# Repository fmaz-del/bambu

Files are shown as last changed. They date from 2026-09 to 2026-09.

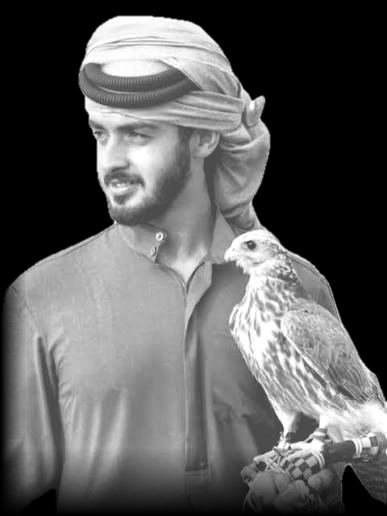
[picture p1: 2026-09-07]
prepared.png

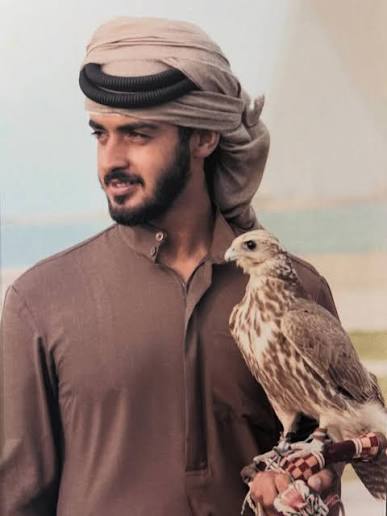
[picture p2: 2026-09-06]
portrait_source.jpg

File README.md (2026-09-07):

# xBloom face cover — picture embossing

Tooling to put a picture on the front of the xBloom Studio cover
(`xbloom_face_v1.5_.3mf`), or on any other STL/3MF model.

## The model

`xbloom_face_v1.5_.3mf` is a Bambu Studio project holding one object,
`xbloom face with straps v1.stl` (4552 triangles), laid on the plate so that
**the visible outer face of the cover points down, at Z = 0**.

Measured from the mesh:

| | |
|---|---|
| overall | 172.4 × 215.7 × 79.9 mm |
| panel wall thickness | 2.9 mm |
| **front panel (flat, usable)** | **X 51.8 … 135.0, Y 16.6 … 232.3 → 83.2 × 215.7 mm** |
| right wing | X 138 … 220 — carries 3 × Ø10 mm holes and a vent slot array |

So the picture goes on the `bottom` face (outward normal −Z), restricted to the
left-hand region — the right-hand part of that face is the side wing and must
stay clear.

The mesh is closed but **not manifold**: 8 bodies, 135 edges shared by 4 faces,
18 duplicate faces, and ~95 zero-thickness triangle pairs left over from the
striped variant. A true CSG boolean therefore fails, and the tool falls back to
merging the shells — slicers union overlapping solids, so an emboss still
prints correctly. An *engrave* would need a repaired mesh first.

## Result

`xbloom_face_raised_0.1mm.3mf` — **print this one.** The portrait stands out of
the panel: the whole panel is lowered 1.4 mm and the figure rises back to the
original surface, 83.2 x 108 mm, seated at the bottom and running the full
panel width. The project's layer height is set to 0.1 mm.

`xbloom_face_raised_0.2mm.3mf` is the same mesh on the original 0.2 mm profile.

The **screen window** on the right wing is also opened up: the original slotted
grille is replaced by a single clear rectangle, **71.6 x 27.3 mm at
X 140.9-212.5, Y 129.7-157.0**, cut through the 2.93 mm plate. The ribs between
the slots covered the display; the three Ø10 mm holes below it are untouched.

```bash
python3 cut_opening.py raised.3mf -o screen.3mf \
    --rect 140.91 129.65 212.51 156.99 --z -2 5
```

Reproduce with:

```bash
python3 prepare.py portrait_source.jpg -o prepared.png --raised \
    --clahe 0.6 --gamma 0.95 --floor 0.30 --feather 1 \
    --fade-bottom 0.14 --fade-left 0.07

python3 emboss.py xbloom_face_v1.5_.3mf prepared.png -o raised.3mf \
    --repair --raised 1.4 --invert --face bottom \
    --region 51.76 16.57 135.0 232.26 --margin 0 --valign bottom \
    --blur 0.4 --resolution 480

python3 set_layer_height.py raised.3mf -o raised_0.1mm.3mf --layer-height 0.1
```

### Raised relief on a face that lies on the build plate

The decorated face sits at Z = 0, on the plate, so relief cannot protrude
outward — there is nothing below Z = 0 to print into. `--raised MM` gets the
raised look while only ever *removing* material: it lowers the whole of
`--region` by MM, then stands the picture back out of that recess so its peaks
finish flush with the original surface. The part still prints face-down with no
supports, and the figure's highest points line up with the wing's face.

### Layer height decides whether it reads as a relief at all

A relief shows only as many tones as it has layers. The first print of this
model, at the project's stock 0.2 mm over a 1.1 mm relief, had five steps:
broad areas of the robe and face all landed on one step and only sharp edges
crossed a layer boundary, so it printed as contour lines rather than a
carving. At 1.4 mm and 0.1 mm layers there are fourteen steps.

That doubles print time over the whole 80 mm part. Bambu Studio's variable
layer height tool can instead hold 0.1 mm for just the bottom 2 mm, where the
relief is, and run 0.2 mm above it.

### Do not lean on CLAHE for a relief

Local contrast equalisation sharpens edges but flattens the broad tonal
gradient that gives a relief its volume — it pushes the result toward
outlines, which is the other half of what went wrong on that first print.
`--clahe 0.6` or lower, and let the global contrast stretch do the work.

### Printing on something other than an X1 Carbon

The project embeds an **X1 Carbon** profile: X1-specific start G-code
(`;===== machine: X1-0.4 =====`), 20000 mm/s^2 axis accelerations, and
`@BBL X1C` filament presets. The *print* settings list the P1S as compatible,
but the *machine* settings are not portable, and rewriting start G-code by hand
is not worth the risk.

`xbloom_face_raised_no_profile.3mf` is the same geometry with that profile
removed (`strip_profile.py`), so the slicer applies the settings for whichever
printer is selected. The model and its position on the plate are unchanged.

**Set the layer height to 0.1 mm after loading it** — without the embedded
profile it will come in at the printer's default 0.2 mm, which is what turned
the first print into contour lines.

The part is 172.4 x 215.7 x 79.9 mm and uses 67% x 84% of a 256 mm bed, so it
fits the P1S, P1P, X1 and A1 alike.

### Printing notes

- Print in the orientation the project already has: decorated face down, no supports.
- 0.2 mm layers give the 1.0 mm carve five tonal steps; **0.1 mm layers give ten**
  and look markedly smoother.
- Use a smooth plate. A textured plate stamps its own pattern over the relief.
- Panel wall is 2.9 mm, so a 1.0 mm carve leaves 1.9 mm behind it.

## Usage

```bash
python3 emboss.py xbloom_face_v1.5_.3mf picture.png -o xbloom_face_picture.3mf \
    --face bottom --region 51.8 16.6 135.0 232.3 --margin 10 \
    --mode emboss --depth 0.6 --preview preview.png
```

`--region` takes the rectangle in the two model axes that lie in the face
(X and Y here); the picture is scaled to fit inside it with `--margin` mm clear.
3MF in and 3MF out preserves the whole Bambu Studio project — print profiles,
plate layout, thumbnails — replacing only the object mesh.

Useful options:

| flag | effect |
|---|---|
| `--depth` | relief height in mm (0.4–0.8 suits a 0.2 mm layer height) |
| `--mode engrave` | cut the picture in instead of raising it |
| `--invert` | raise the light pixels rather than the dark ones |
| `--threshold 0.5` | binarise, for a crisp flat-topped logo |
| `--rotate 180` | turn the picture on the face |
| `--valign/--halign` | sit against an edge of `--region` instead of its middle |
| `--offset-x/--offset-y` | nudge in mm along the face axes |
| `--resolution` | pixels along the longest side; drives the triangle count |
| `--keep-framing` | honour an off-centre subject instead of centring it |

## Dependencies

```bash
pip3 install numpy pillow trimesh manifold3d networkx matplotlib
```

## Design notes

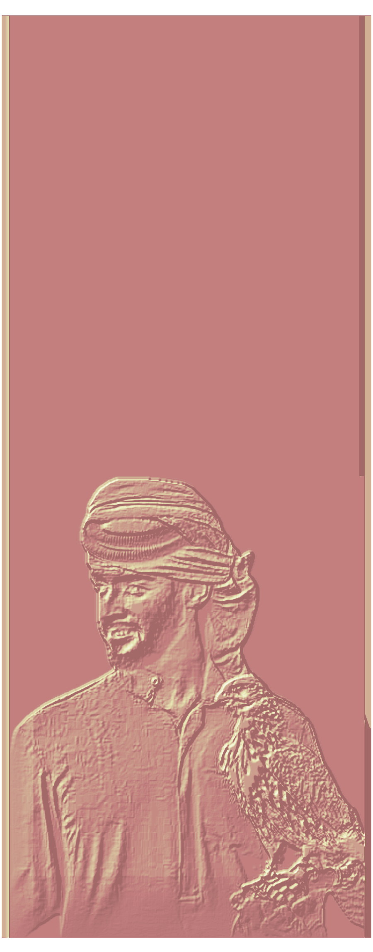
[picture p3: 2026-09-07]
preview_panel.png

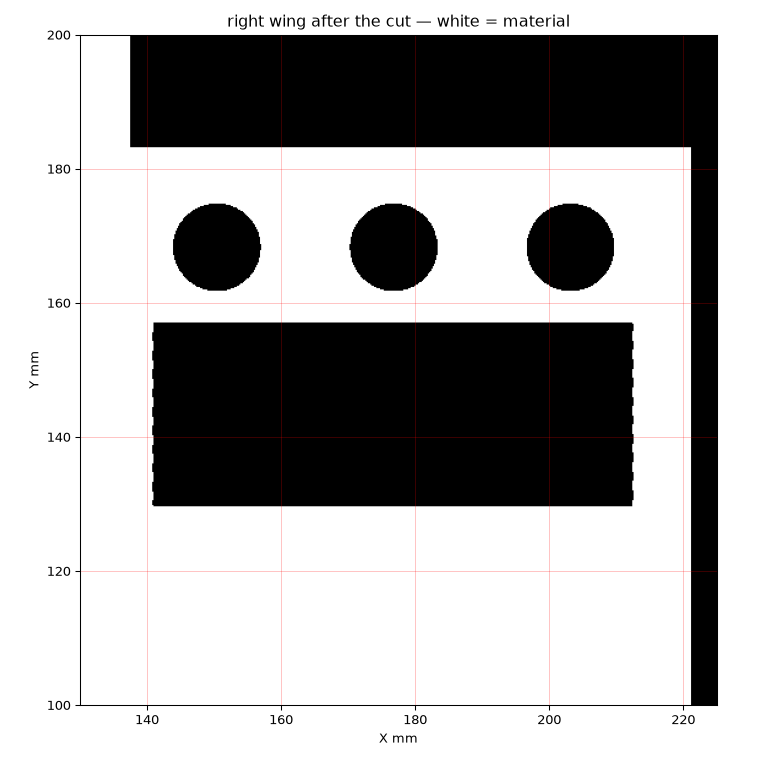
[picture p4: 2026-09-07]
preview_screen_window.png

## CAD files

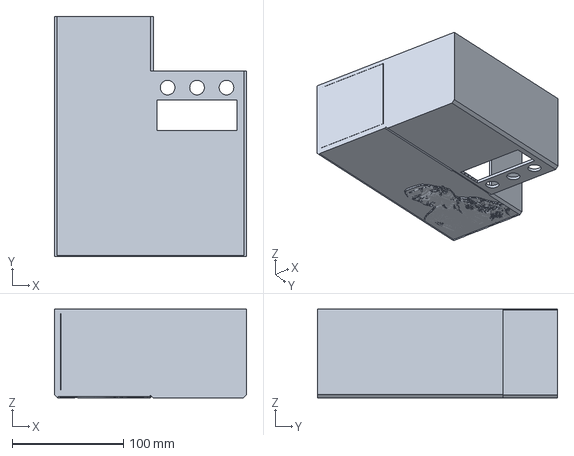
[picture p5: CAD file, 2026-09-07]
xbloom_face_raised_no_profile.3mf
172.4 x 215.7 x 79.9 mm

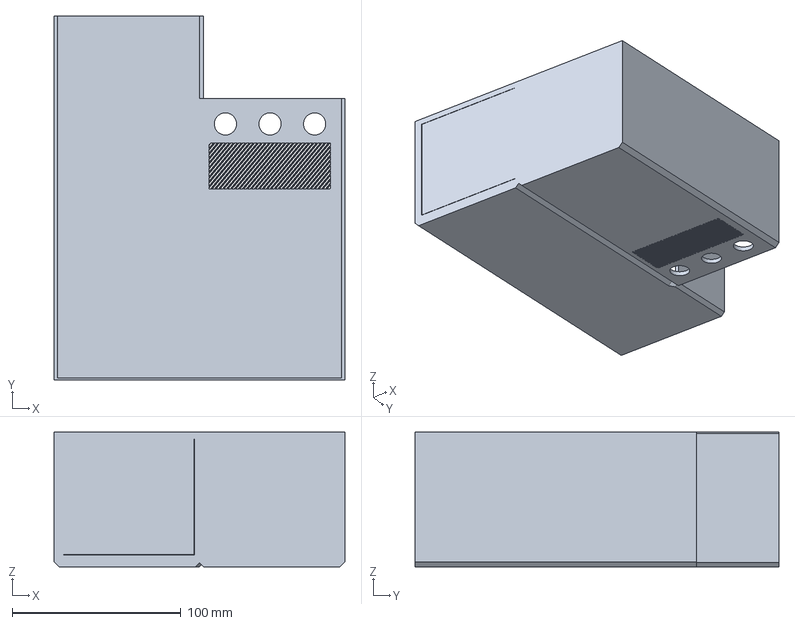
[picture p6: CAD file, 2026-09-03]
xbloom_face_v1.5_.3mf
172.4 x 215.7 x 79.9 mm

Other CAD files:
xbloom_face_raised.stl
xbloom_face_raised_0.2mm.3mf
xbloom_face_raised_0.1mm.3mf

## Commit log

2026-09-03 Add picture-embossing tool for the xBloom face cover
    emboss.py turns an image into a height map, builds it as a closed solid and
    booleans it onto a named face of an STL or 3MF model. Background pixels get
    zero height and stay buried inside the part, so only the ink shows as relief
    rather than a raised slab.
    3MF in and 3MF out rewrites only the object mesh inside the archive, keeping
    the Bambu Studio project (print profiles, plate layout, thumbnails) intact.
    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
    [xbloom_face_v1.5_.3mf]
2026-09-03 Carve the portrait into the cover's left panel
    Adds the pieces needed to put a photograph on the xBloom cover as a bas-relief:
    - repair.py cleans the published mesh into one watertight solid. The 3MF is
    closed but non-manifold -- duplicate faces, ~95 zero-thickness triangle pairs
    from the striped variant, and seven uncapped boundary loops where the stripe
    recesses were modelled. Nothing could be booleaned against it before.
    - prepare.py masks the subject out of its background so the carving is bounded
    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
    [xbloom_face_portrait.3mf, xbloom_face_portrait.stl]
2026-09-06 Sit the portrait at the bottom of the panel
    Adds --valign and --halign, which park the picture against an edge of --region
    rather than in its middle, and rebuilds the cover with the portrait at the
    bottom of the panel. Beats hand-computing an offset, and the alignment holds
    if the picture is later resized.
    Claude-Session: https://claude.ai/code/session_0117M7LrdVcnop2RkF7jUh8U
    [xbloom_face_portrait.3mf, xbloom_face_portrait.stl]
2026-09-06 Add --aspect to crop a picture to a panel's proportions
    The cover's panel is 83 x 216 mm but the portrait is square, so fitting it by
    width leaves it filling only a third of the panel. --aspect centre-crops the
    picture to a given width:height ratio around the subject, so it can be scaled
    to the panel's full width and still fill a useful share of its height.
    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
2026-09-06 Merge near-coincident vertices before writing a 3MF
    The 3MF writer formats coordinates to seven decimals. Manifold's boolean can
    leave vertex pairs a fraction of a nanometre apart, and rounding collapsed
    those pairs, so a mesh that was watertight in memory reloaded with six
    zero-area faces and two non-manifold edges. Merging at 1e-5 mm first -- far
    below anything a printer resolves, but coarse enough that rounding cannot
    collapse it -- and dropping degenerate faces keeps the written file clean.
    Also adds the full-panel-width variants: the portrait now runs edge to edge
    rather than sitting inside a margin, at 480 px across (~0.17 mm per pixel) and
    1.1 mm deep. xbloom_face_portrait is cropped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
    [xbloom_face_portrait.3mf, xbloom_face_portrait.stl, xbloom_face_portrait_square.3mf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]
2026-09-06 Write 3MF vertices losslessly instead of rounding them
    Formatting coordinates to seven decimals collapsed vertex pairs that the
    boolean leaves a fraction of a nanometre apart, so a mesh that was watertight
    in memory reloaded with zero-area faces and non-manifold edges.
    The previous commit tried to fix this by merging vertices and then dropping
    degenerate faces by height, but that threshold also caught legitimate thin
    slivers and removing them punched real holes -- the output came back not
    watertight at all, which is worse than the defect it was meant to fix.
    Writing each coordinate with repr(), the shortest string that round-trips a
    float exactly, removes the cause: no merging, no face rem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
2026-09-06 Recarve from the sharper source photo
    The second photo is 4.5x sharper by variance-of-Laplacian and natively 3:4, so
    it fills the panel at 83.2 x 107.5 mm with no cropping -- the whole falcon and
    the glove stay in frame, where the 1:1.5 crop of the square photo clipped the
    bird's tail at the panel edge. At 387 px across an 83 mm panel it is still
    0.21 mm per pixel, finer than a 0.4 mm nozzle resolves.
    Documents how to verify a written 3MF: reload with process=False so trimesh
    does not merge vertices on the way in and hide what the file actually holds.
    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
    [xbloom_face_portrait.3mf, xbloom_face_portrait.stl, xbloom_face_portrait_square.3mf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]
2026-09-07 Add raised relief, and stop CLAHE flattening the form
    The first print came out as contour lines rather than a carving. Two causes:
    - The project slices at 0.2 mm, so a 1.1 mm relief had only five tonal steps.
    Broad gradients landed on a single step and only sharp edges crossed a layer
    boundary, which is what printed. set_layer_height.py sets the project to
    0.1 mm, doubling the steps.
    - CLAHE equalises local regions, which strips the broad tonal gradient that
    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
2026-09-07 Ship the raised portrait at 0.1 mm layers
    Replaces the carved-in cover with the raised one: the panel is lowered 1.4 mm
    and the figure stands back out to the original surface, 83.2 x 108 mm at the
    bottom of the panel.
    Verified on the written file, in plate coordinates: 236156 triangles, all
    354234 edges at valence 2, watertight, bounds identical to the original, all
    29 archive entries intact. The panel face spans z 0 to 1.4 mm with tones spread
    across the range rather than piled on two levels.
    Documents why layer height and CLAHE, not the carve, produced the contour-line
    first print.
    Claude-Session: https://claude.ai/code/session_0117M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
    [xbloom_face_portrait.3mf, xbloom_face_portrait.stl, xbloom_face_raised.stl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]
2026-09-07 Open the screen window on the right wing
    The slotted grille sat over the machine's display, so the ribs between the
    slots blocked it. cut_opening.py replaces the grille with a single clear
    rectangle spanning its outer bounds, 71.6 x 27.3 mm through the 2.93 mm plate,
    removing 2.00 cm3 of ribs. The three holes below are untouched, and the tool
    reports the Z span of everything in the cut column first so the side wall at
    X 221 cannot be caught by accident.
    Verified on the written file: 235604 triangles, all 353406 edges at valence 2,
    watertight, no geometry left inside the window, bounds unchanged, archive
    intact.
    Claude-Session: https://c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
    [xbloom_face_raised.stl, xbloom_face_raised_0.1mm.3mf, xbloom_face_raised_0.2mm.3mf]
2026-09-07 Add a printer-agnostic 3MF for non-X1C machines
    The project embeds an X1 Carbon machine profile: X1-specific start G-code,
    20000 mm/s^2 accelerations and @BBL X1C filament presets. The print settings
    declare the P1S compatible but the machine settings are not, and rewriting
    start G-code by hand risks the print and the printer.
    strip_profile.py drops Metadata/project_settings.config and keeps everything
    else, so the slicer applies the selected printer's own settings. Geometry and
    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
    [xbloom_face_raised_no_profile.3mf]
